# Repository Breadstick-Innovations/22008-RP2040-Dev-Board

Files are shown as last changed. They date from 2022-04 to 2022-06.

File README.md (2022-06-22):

# RP2040 Dev Board
I wanted to get myself more aquainted with JLCPCB's SMT assembly service, so I designed a board to their specs and tried to use their basic parts wherever possible, to minimize $3 loading fees for extended parts. My hope is to save time for others who are also interested in the RP2040 and JLCPCB's assembly service. If you put this design in your KiCad templates folder, it'll be quick and easy to iterate from.

 [Here's a link to the dev thread on Twitter.](https://twitter.com/RangenMichael/status/1531419000948723712?s=20&t=70S1JhFAgyq_hug58spnyA)
 
## Where To Buy
* [Tindie](https://www.tindie.com/products/breadstick/rp2040-dev-board/)
* [Breadstick.ca](https://shop.breadstick.ca/products/rp2040-dev-board)

## CircuitPython (Adafruit)
* [Firmware (.uf2)](https://circuitpython.org/board/raspberry_pi_pico/)
* [Tutorial](https://learn.adafruit.com/getting-started-with-raspberry-pi-pico-circuitpython/overview)
* [Essentials](https://learn.adafruit.com/circuitpython-essentials)
* [Docs](https://docs.circuitpython.org/en/latest/docs/index.html)
* [Mu (CircuitPython Code Editor)](https://codewith.mu/)
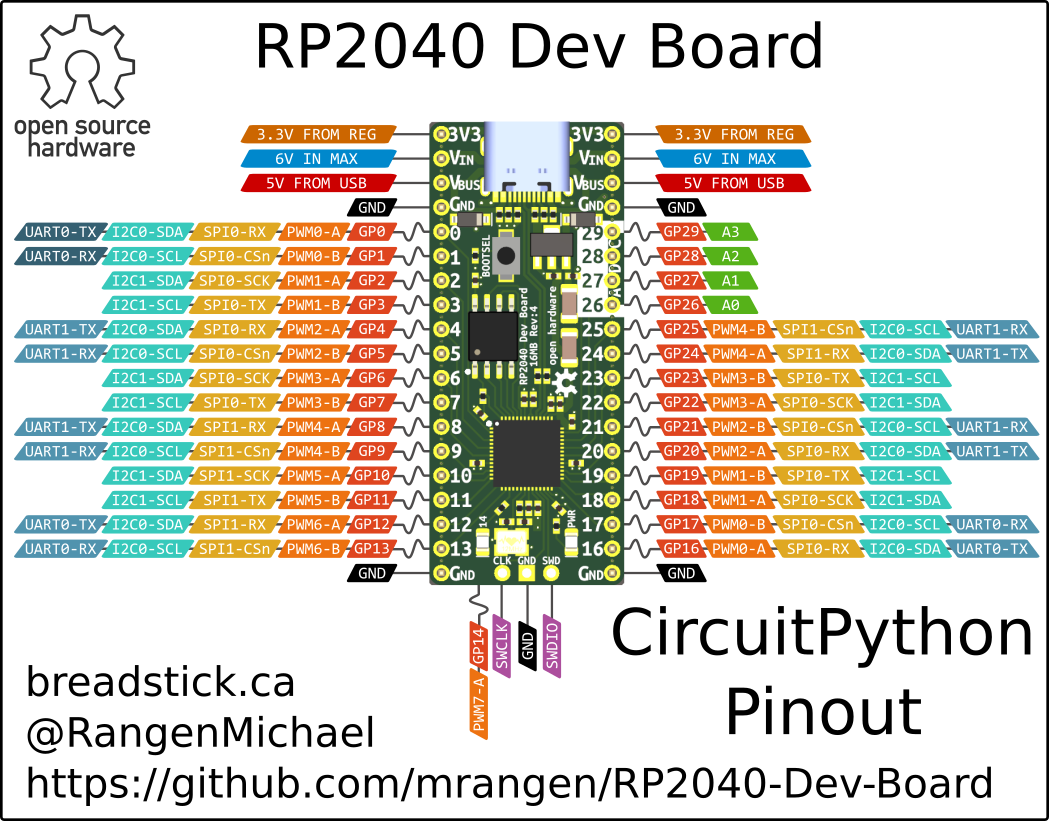
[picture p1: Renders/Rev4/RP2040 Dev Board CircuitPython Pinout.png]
CircuitPython Pinout Diagram
* 

## MicroPython
* [Firmware (.uf2)](https://micropython.org/download/rp2-pico/)
* [Tutorial](https://www.youtube.com/watch?v=JCk9QaCH5QU&list=PLEBQazB0HUyQO6rJxKr2umPCgmfAU-cqR&index=6)
* [QuickRef](https://docs.micropython.org/en/latest/rp2/quickref.html)
* [Docs](https://docs.micropython.org/en/latest/index.html)
* [Thonny (Python IDE)](https://thonny.org/)
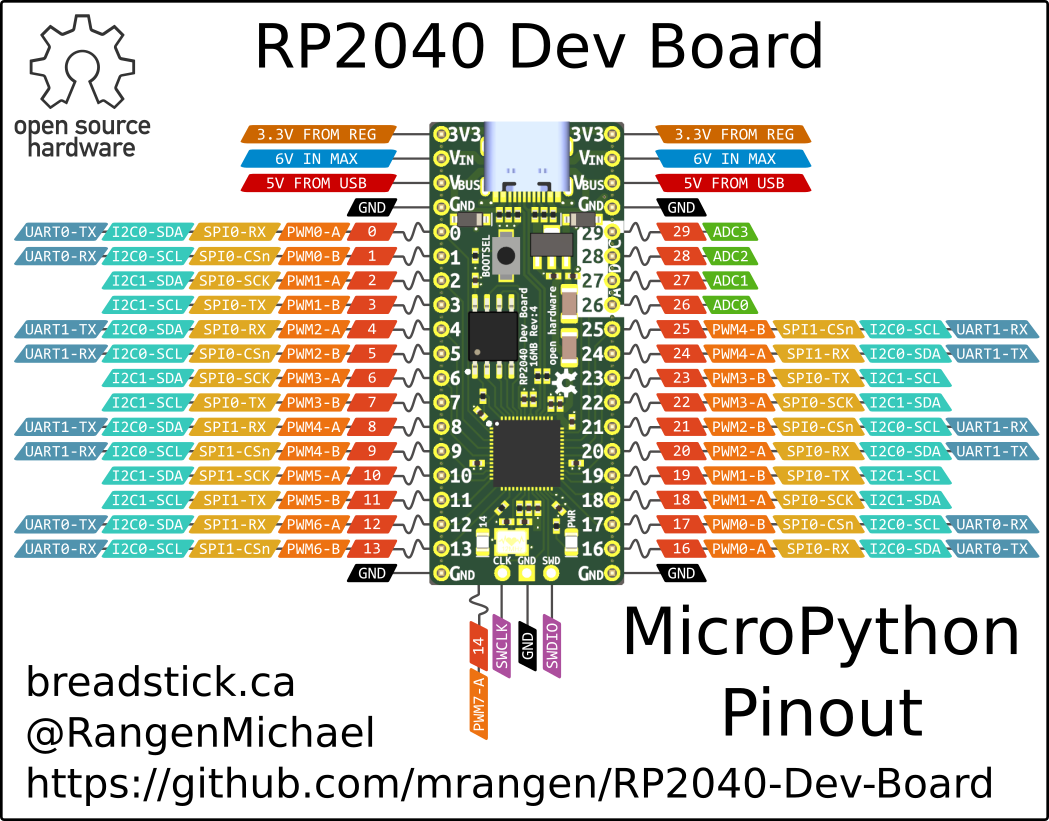
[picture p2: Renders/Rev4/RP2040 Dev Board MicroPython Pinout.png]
MicroPython Pinout Diagram


## Mechanical Drawing
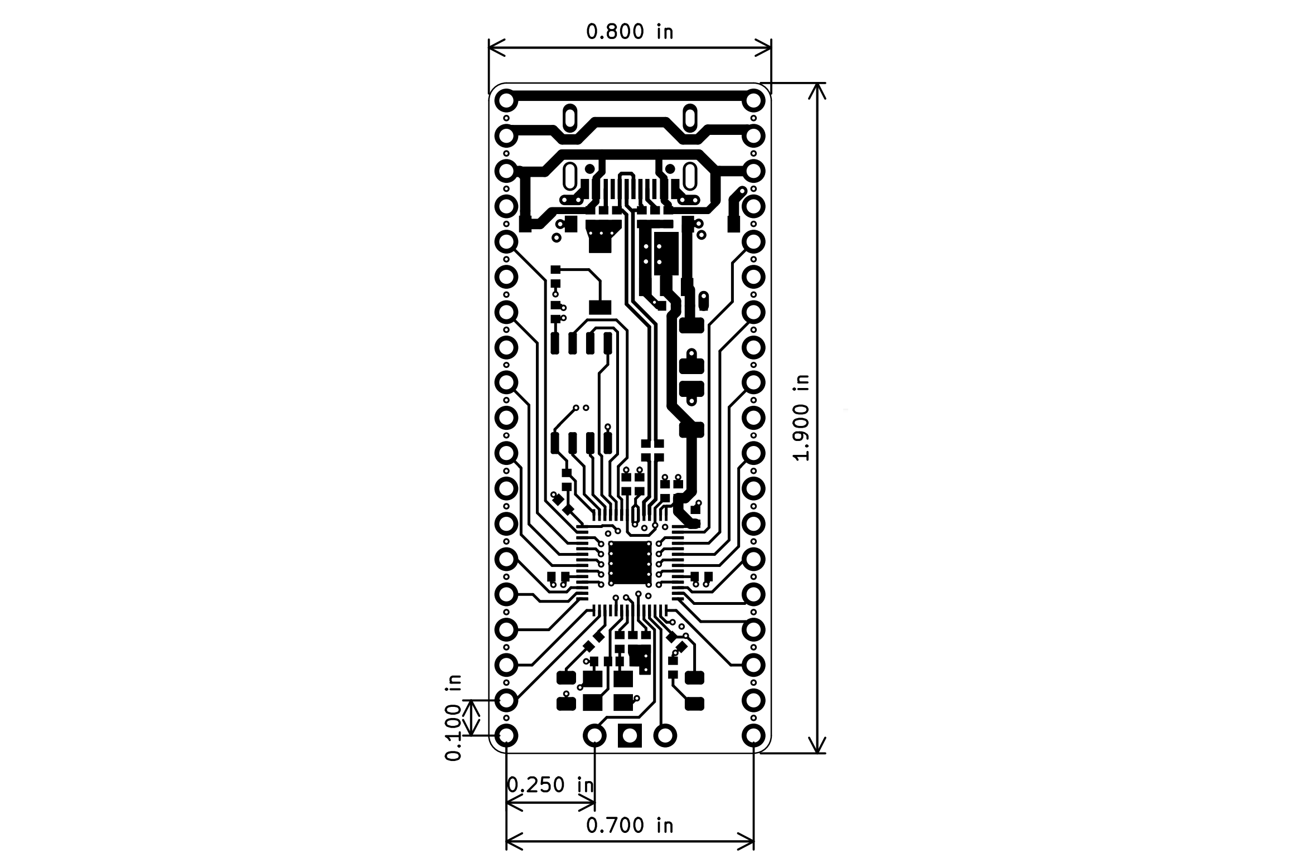
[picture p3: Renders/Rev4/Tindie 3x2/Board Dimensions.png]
Board Diagram


## Fritzing Model (Work In Progress)
Fritzing Model

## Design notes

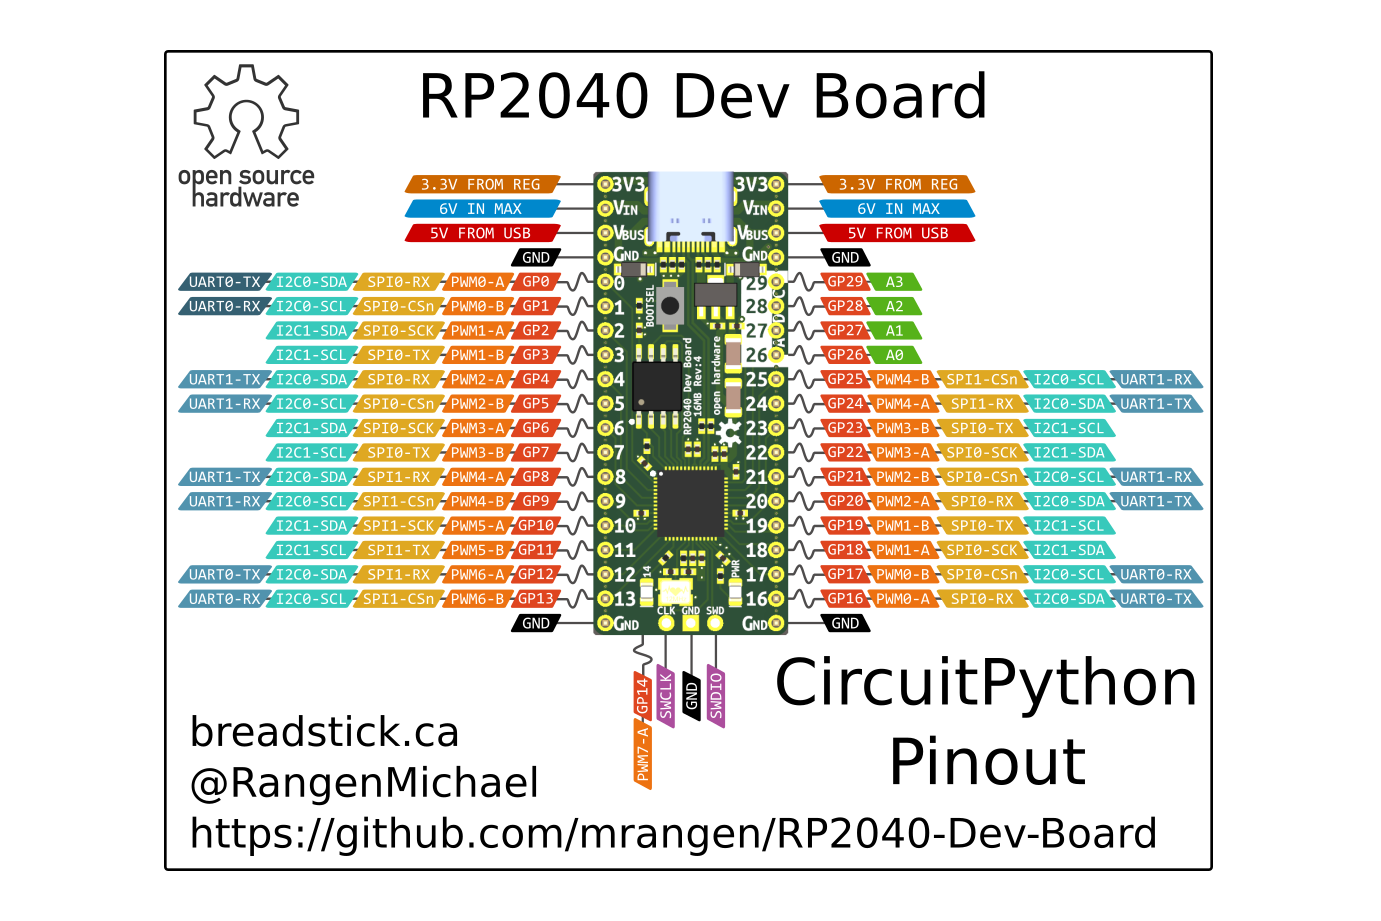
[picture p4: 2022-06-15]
Renders/Rev4/Tindie 3x2/RP2040 Dev Board CircuitPython Pinout.png

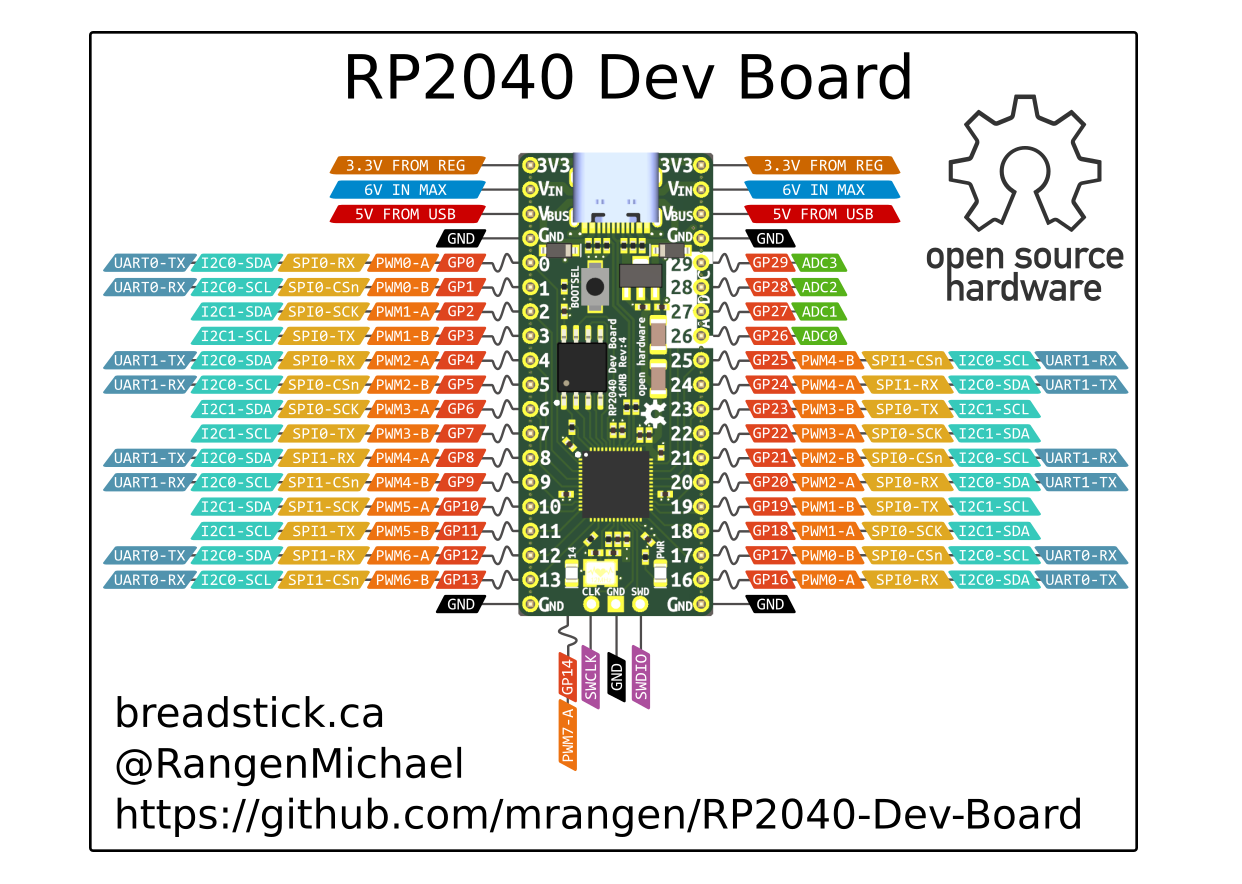
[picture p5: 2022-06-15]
Renders/Rev4/Tindie 3x2/RP2040 Dev Board Pinout.png

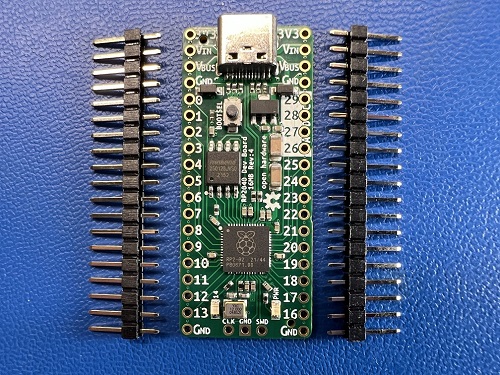
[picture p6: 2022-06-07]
Photos/Rev 4/RP2040 Dev Board with Header Pins Blue Background Front - Thumb.JPG

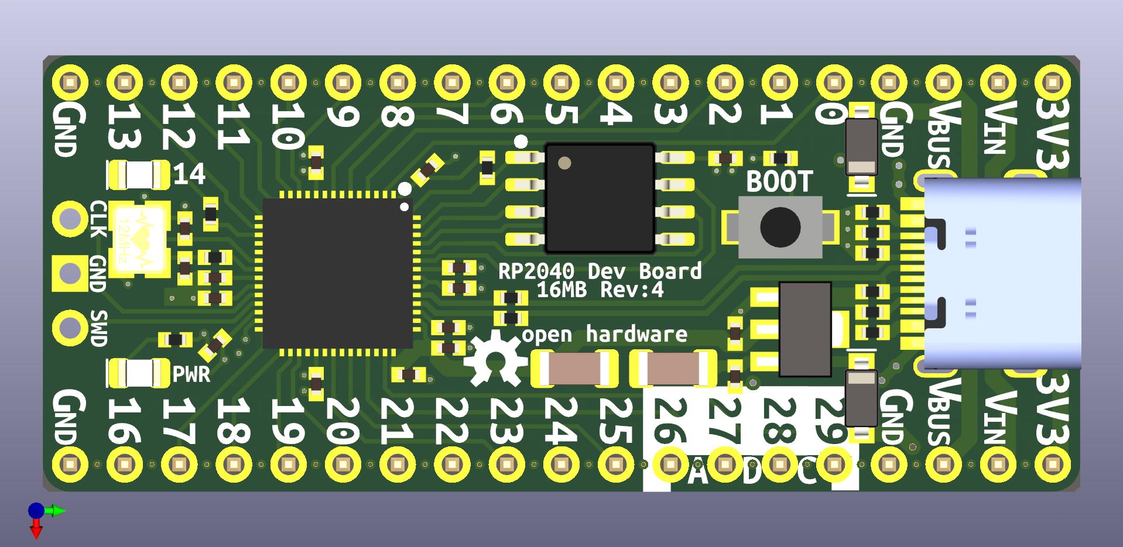
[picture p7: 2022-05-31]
Renders/Rev4/RP2040 Dev Board Front.jpg

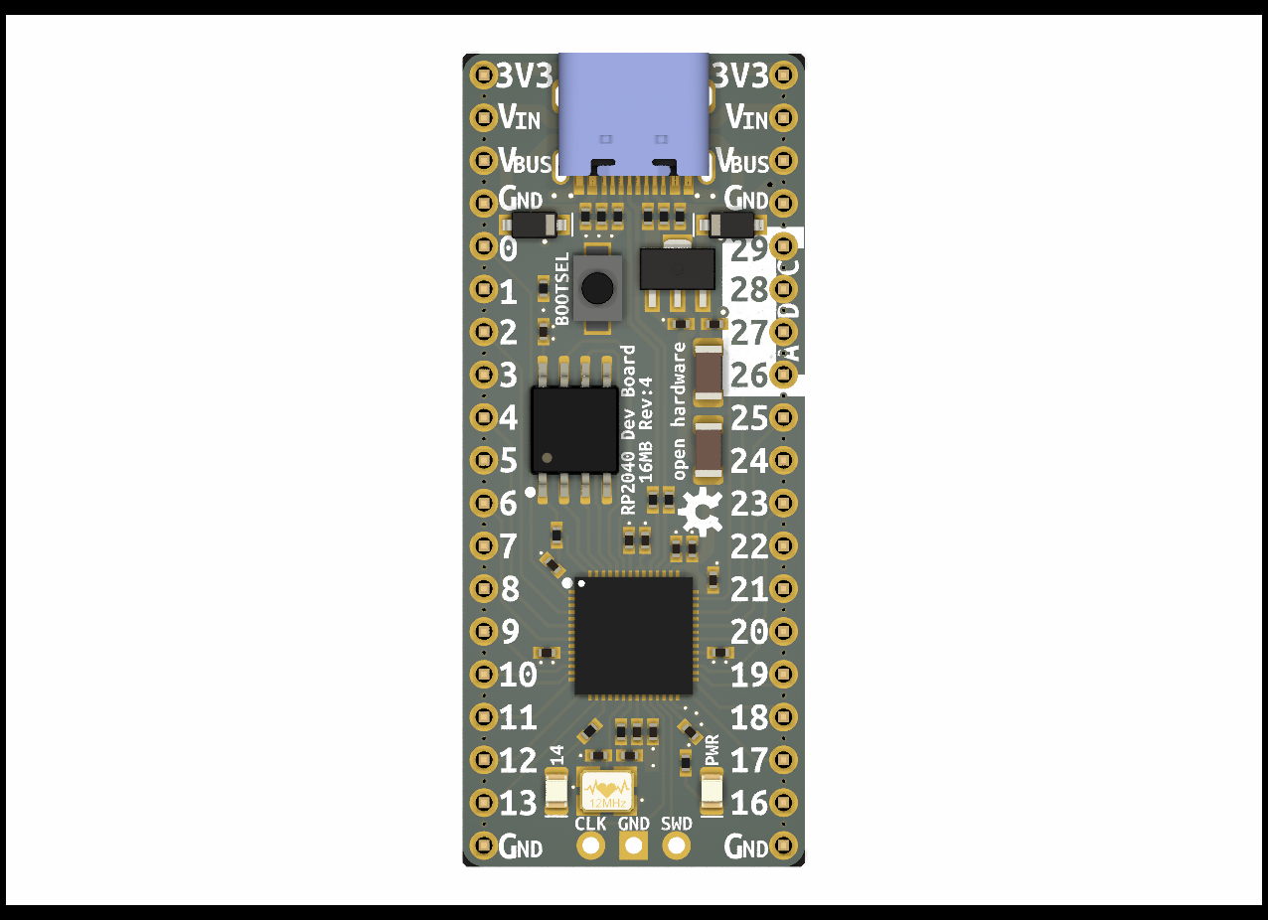
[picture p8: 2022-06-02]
Renders/Rev4/RP2040 Dev Board Front Isometric White Background Raytraced.png

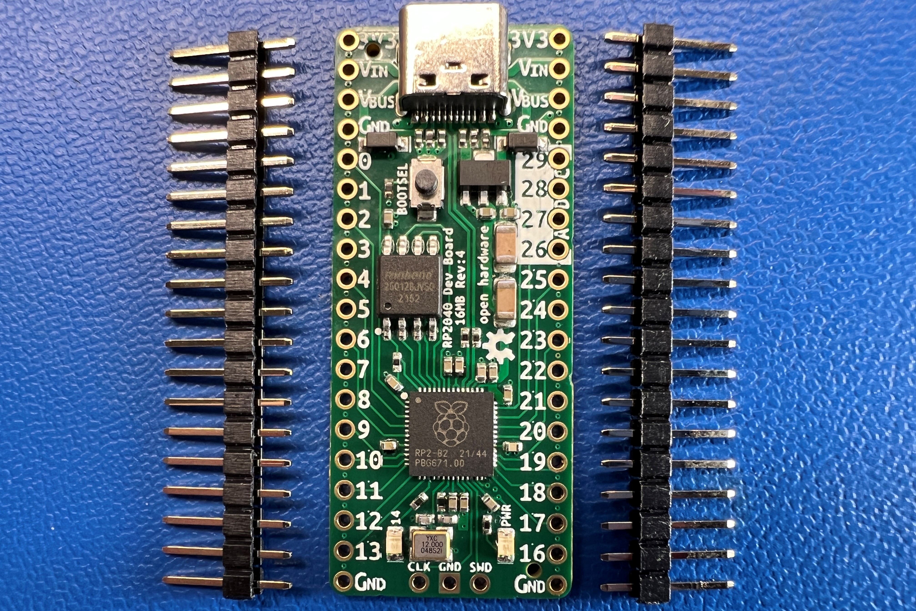
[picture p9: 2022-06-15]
Photos/Rev 4/Tindie 3x2/RP2040 Dev Board with Header Pins Blue Background Front.JPG

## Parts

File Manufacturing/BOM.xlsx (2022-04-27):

Comment | Designator | Footprint | LCSC Part Number
10uF | C201, C202, C204, C205, C207, C208, C212, C213, C215, C216, C218, C219, C221, C222 | 0402 | C15525
30pF | C203, C206 | 0402 | C1570
100uF | C209, C210 | 1206 | C15008
LED_Filled | D101, D102 | 0805 | C2297
SHOTTKY | D103, D104 | SOD-123 | C8598
ESD_TVS | D201, D202, D203, D205 | 0402 | C316049
Conn_01x19 | J101, J102 | Connector_PinHeader_2.54mm:PinHeader_1x19_P2.54mm_Vertical | DNP
Conn_01x03 | J103 | Connector_PinHeader_2.54mm:PinHeader_1x03_P2.54mm_Horizontal | DNP
TYPE-C-31-M-12 | J201 | TYPE-C-31-M-12:HRO_TYPE-C-31-M-12 | C165948
10k | R101, R102, R213 | 0402 | C25744
1k | R201, R211 | 0402 | C11702
27 | R203, R204 | 0402 | C25100
5k1 | R212, R214 | 0402 | C25905
~{USB_BOOT} | SW202 | SW-SMD-2_2.9x3.9x1.7 | C843669
AZ1117R-3.3TRE1 | U201 | SOT-89-3 | C108493
RP2040 | U202 | QFN40P700X700X90-57N | C2040
W25Q128JVS | U205 | SOIC-8_5.23x5.23mm_P1.27mm | C97521
12MHz ±30ppm 20pF 80Ω | Y201 | SMD-3225_4P | C9002

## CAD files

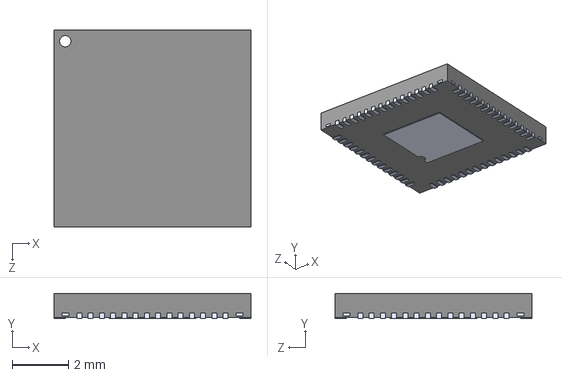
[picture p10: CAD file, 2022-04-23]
Snap EDA/RP2040/RP2040.step
7.00 x 0.9 x 7.00 mm

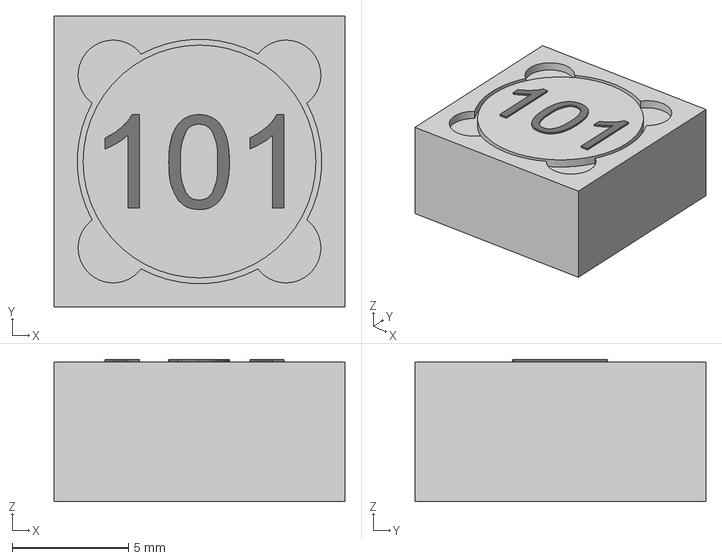
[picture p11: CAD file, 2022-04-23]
Snap EDA/SWRB1205S-101MT v2.step
12.5 x 12.5 x 6.10 mm

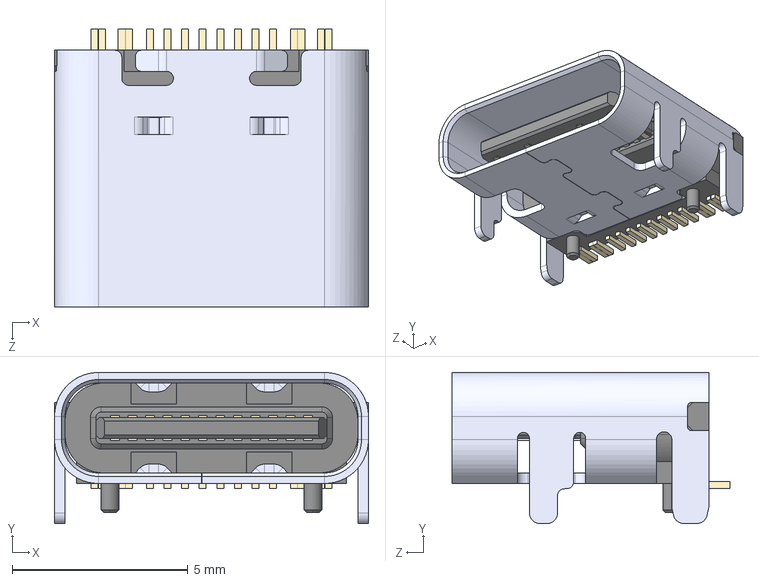
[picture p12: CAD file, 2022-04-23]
Snap EDA/TYPE-C-31-M-12/TYPE-C-31-M-12.step
8.94 x 4.30 x 7.90 mm

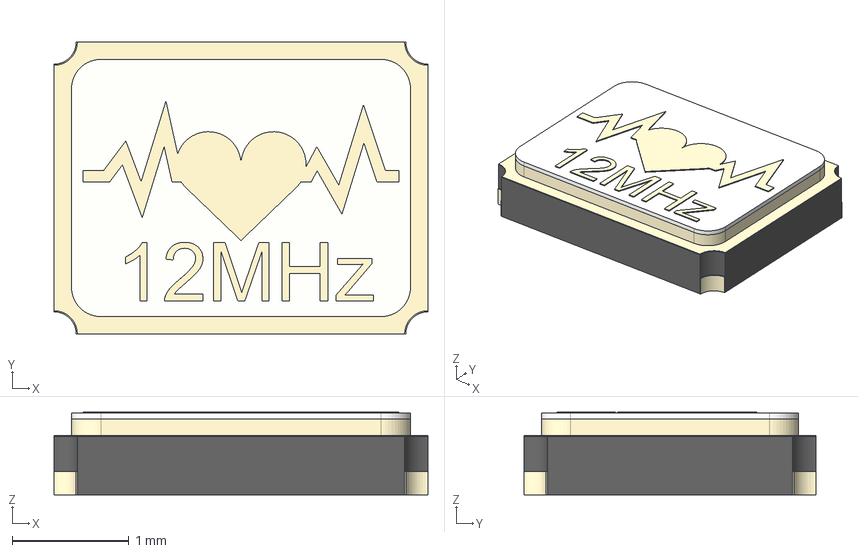
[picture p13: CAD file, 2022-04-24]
Snap EDA/X322516MLB4SI/Crystal3225_24GND.step
3.20 x 2.50 x 0.71 mm

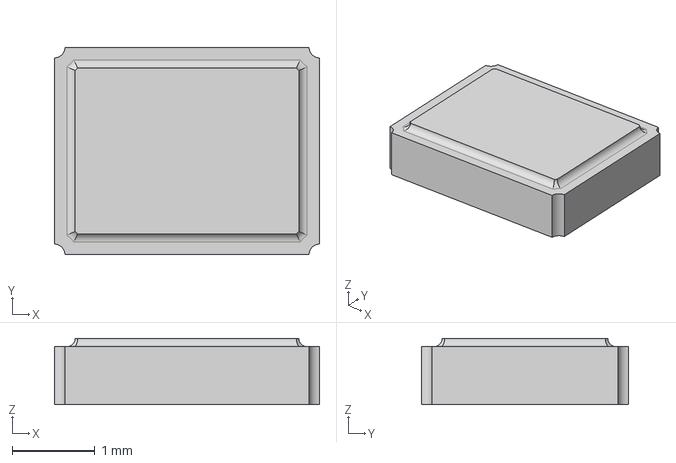
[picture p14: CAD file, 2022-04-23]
Snap EDA/7V12000018 v4.step
3.20 x 2.50 x 0.8 mm

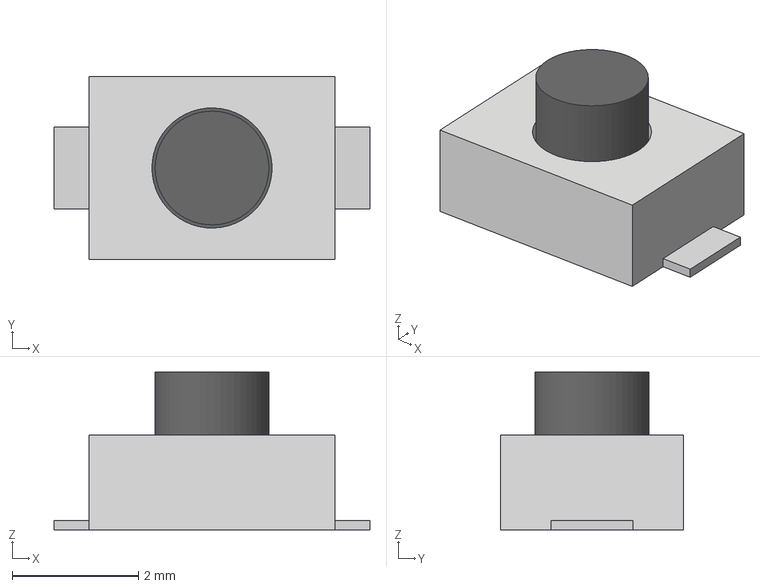
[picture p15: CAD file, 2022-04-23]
Snap EDA/GT-TC029B-H025-L1N v1.step
5.00 x 2.90 x 2.50 mm

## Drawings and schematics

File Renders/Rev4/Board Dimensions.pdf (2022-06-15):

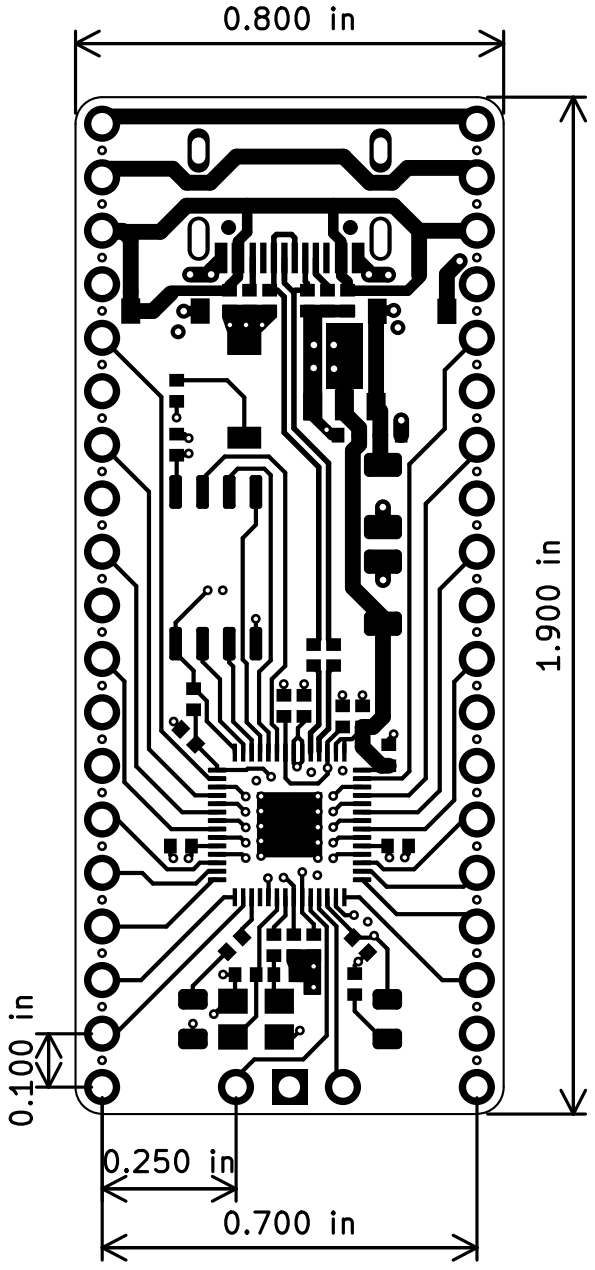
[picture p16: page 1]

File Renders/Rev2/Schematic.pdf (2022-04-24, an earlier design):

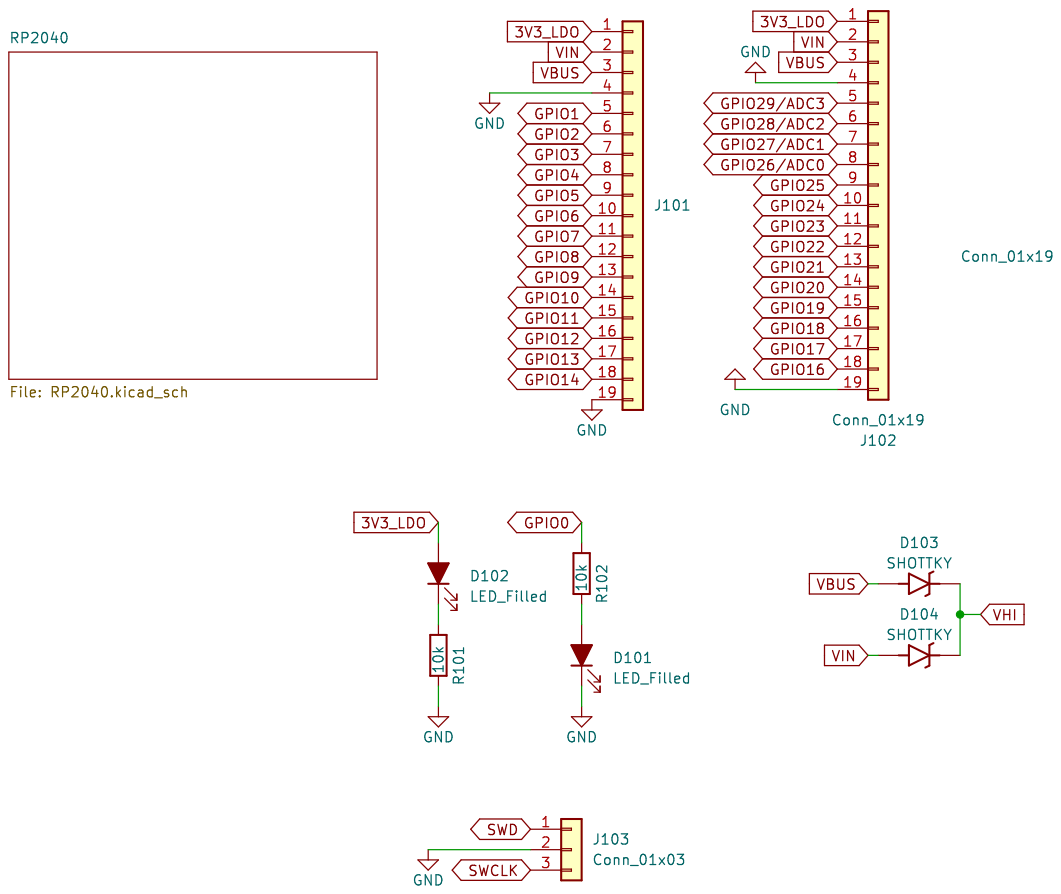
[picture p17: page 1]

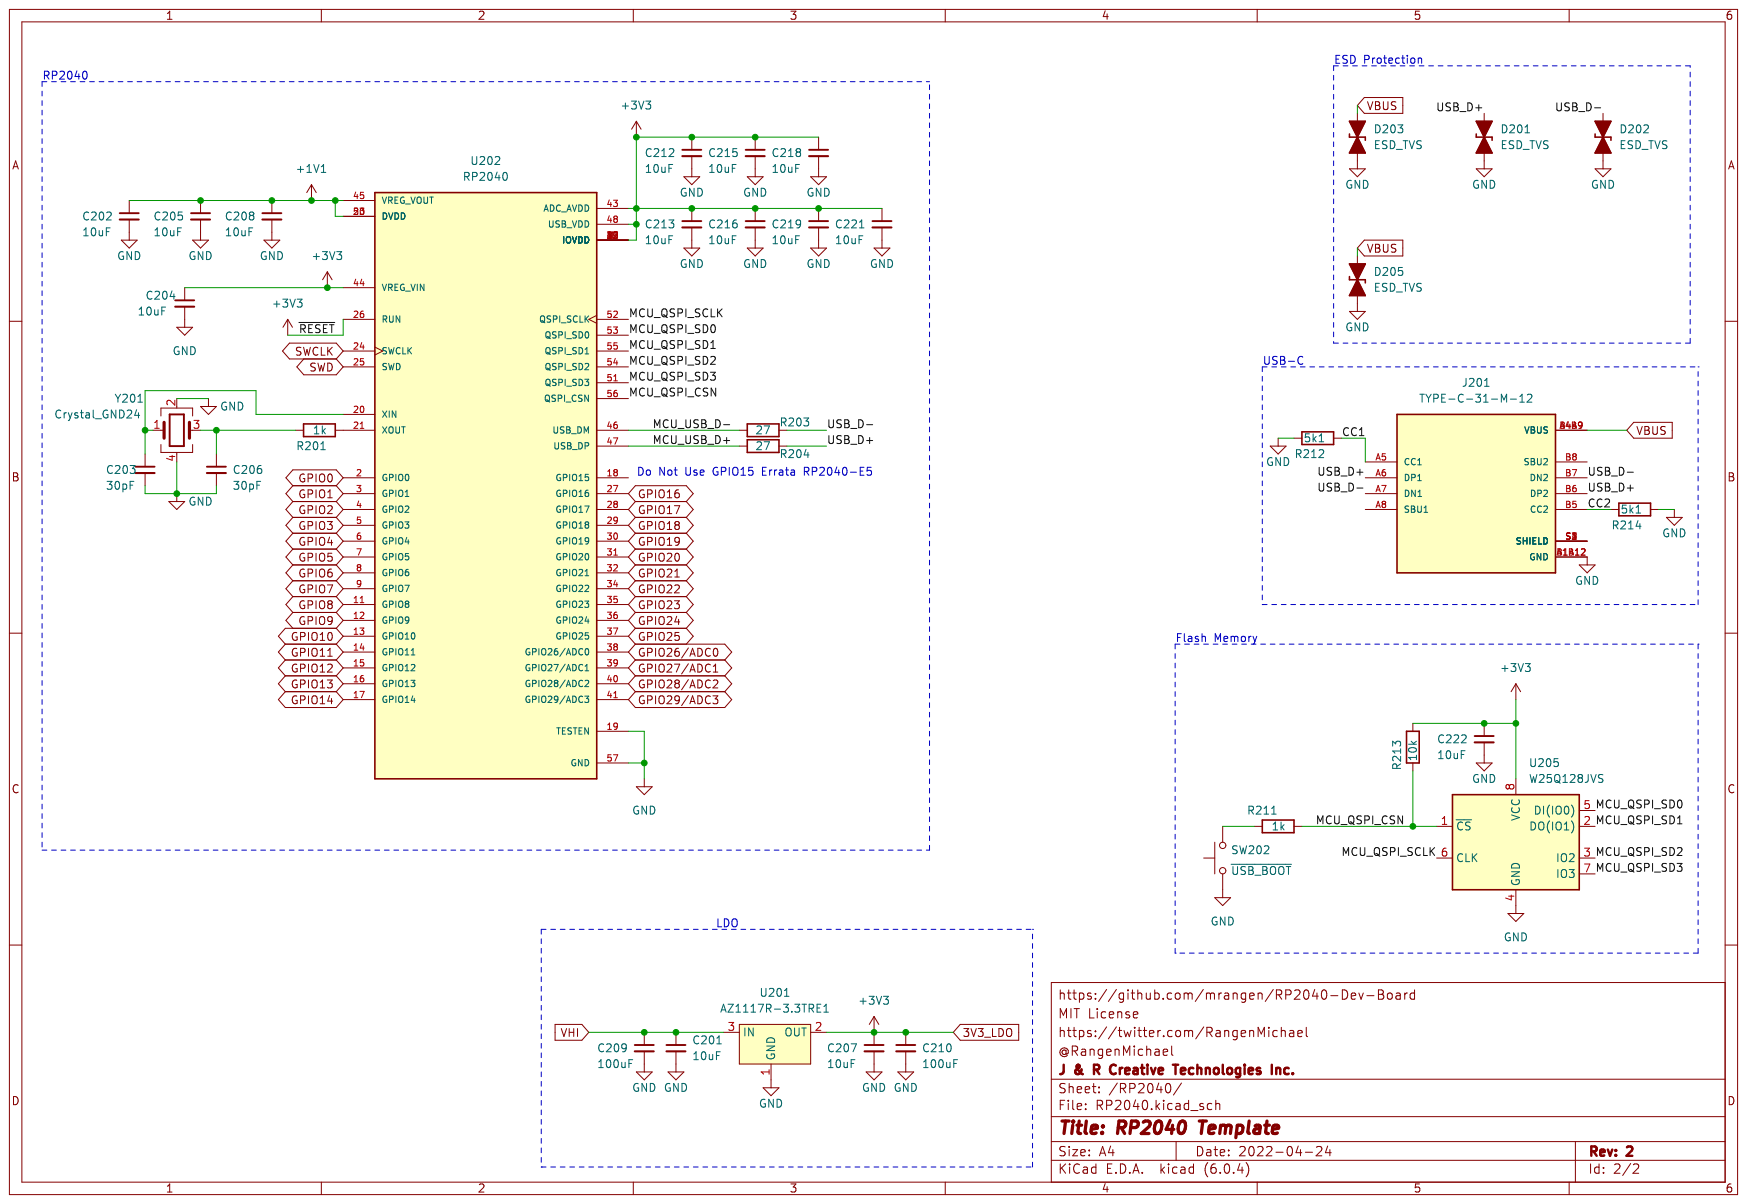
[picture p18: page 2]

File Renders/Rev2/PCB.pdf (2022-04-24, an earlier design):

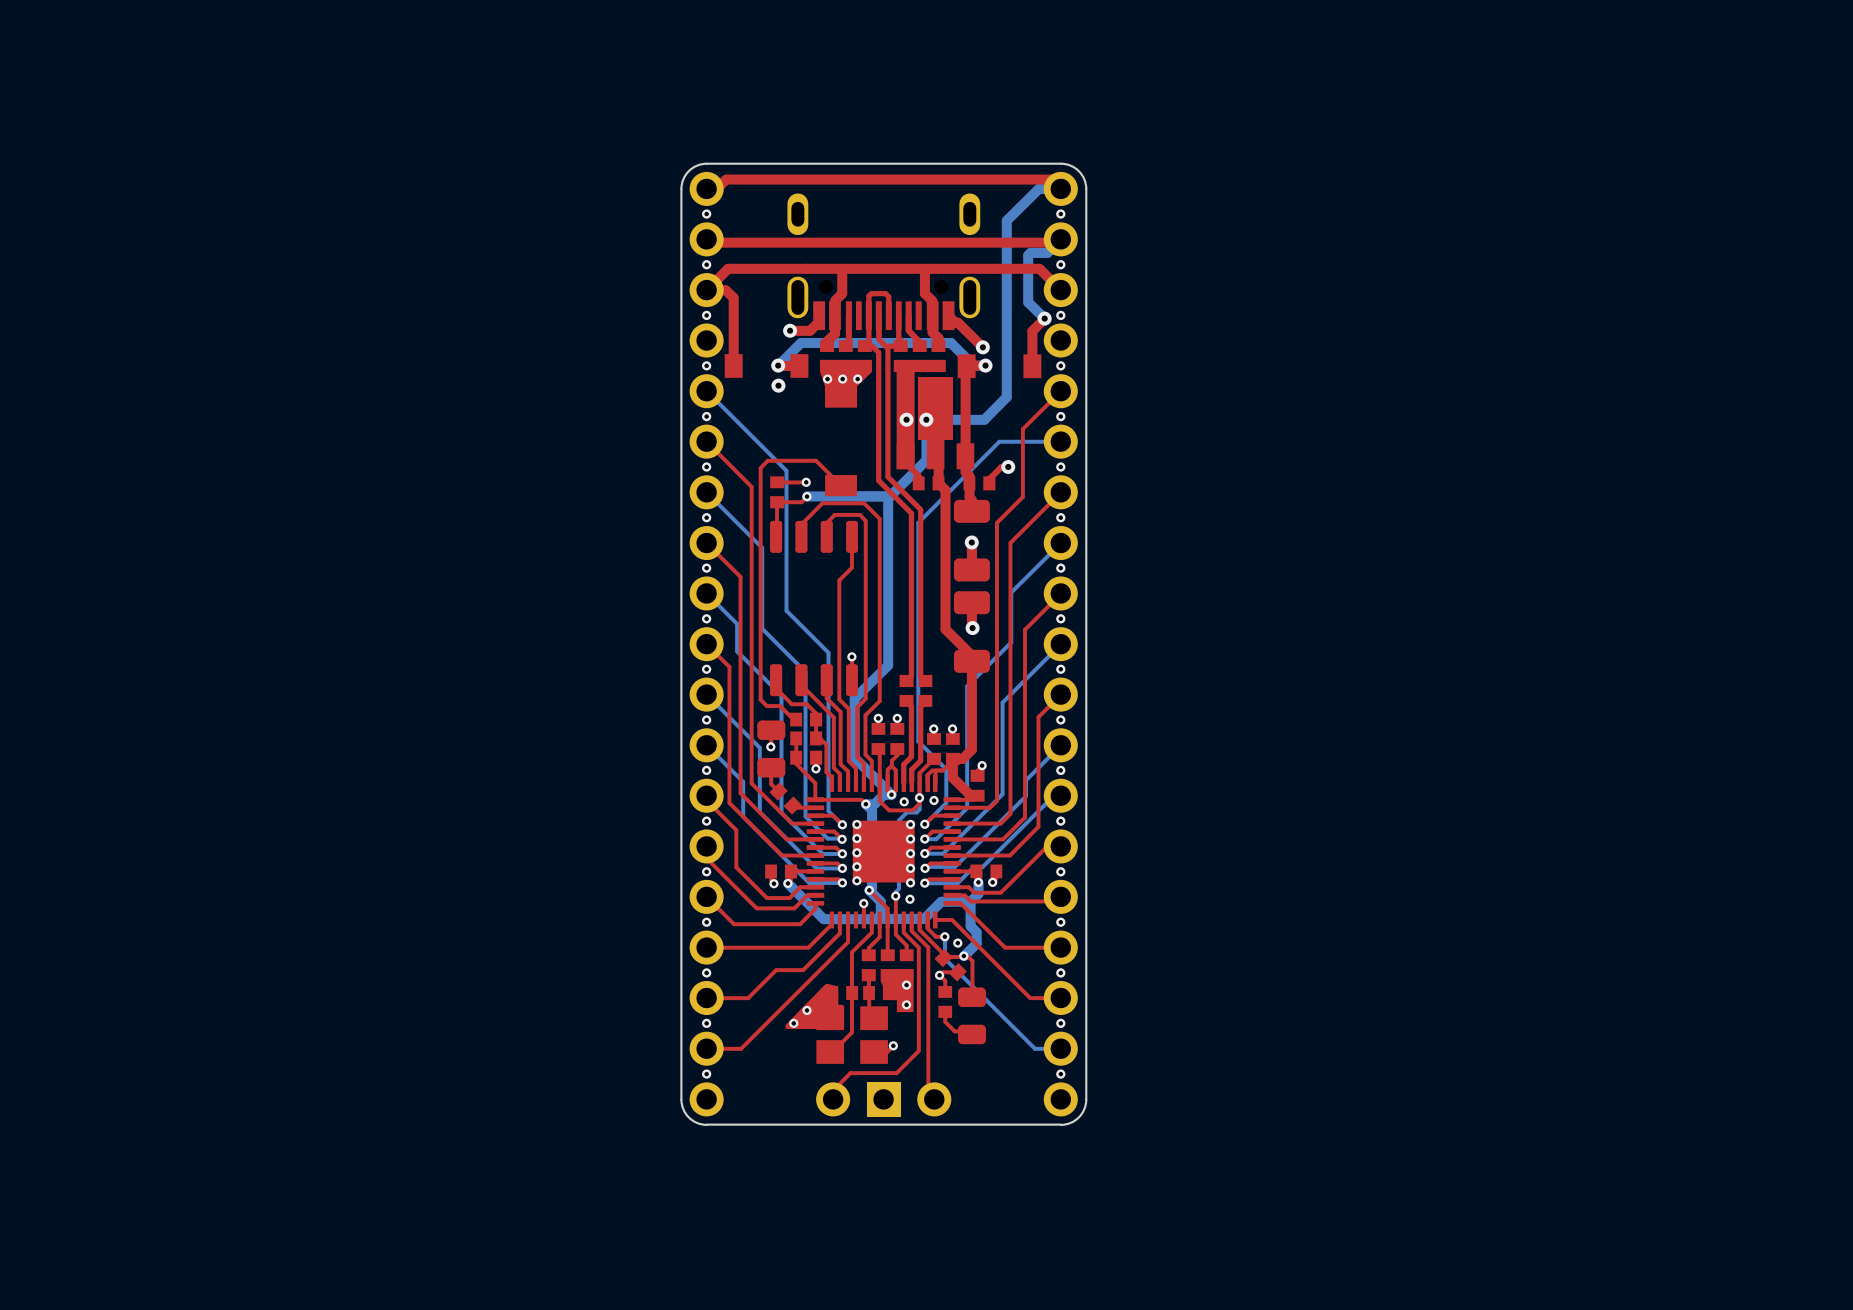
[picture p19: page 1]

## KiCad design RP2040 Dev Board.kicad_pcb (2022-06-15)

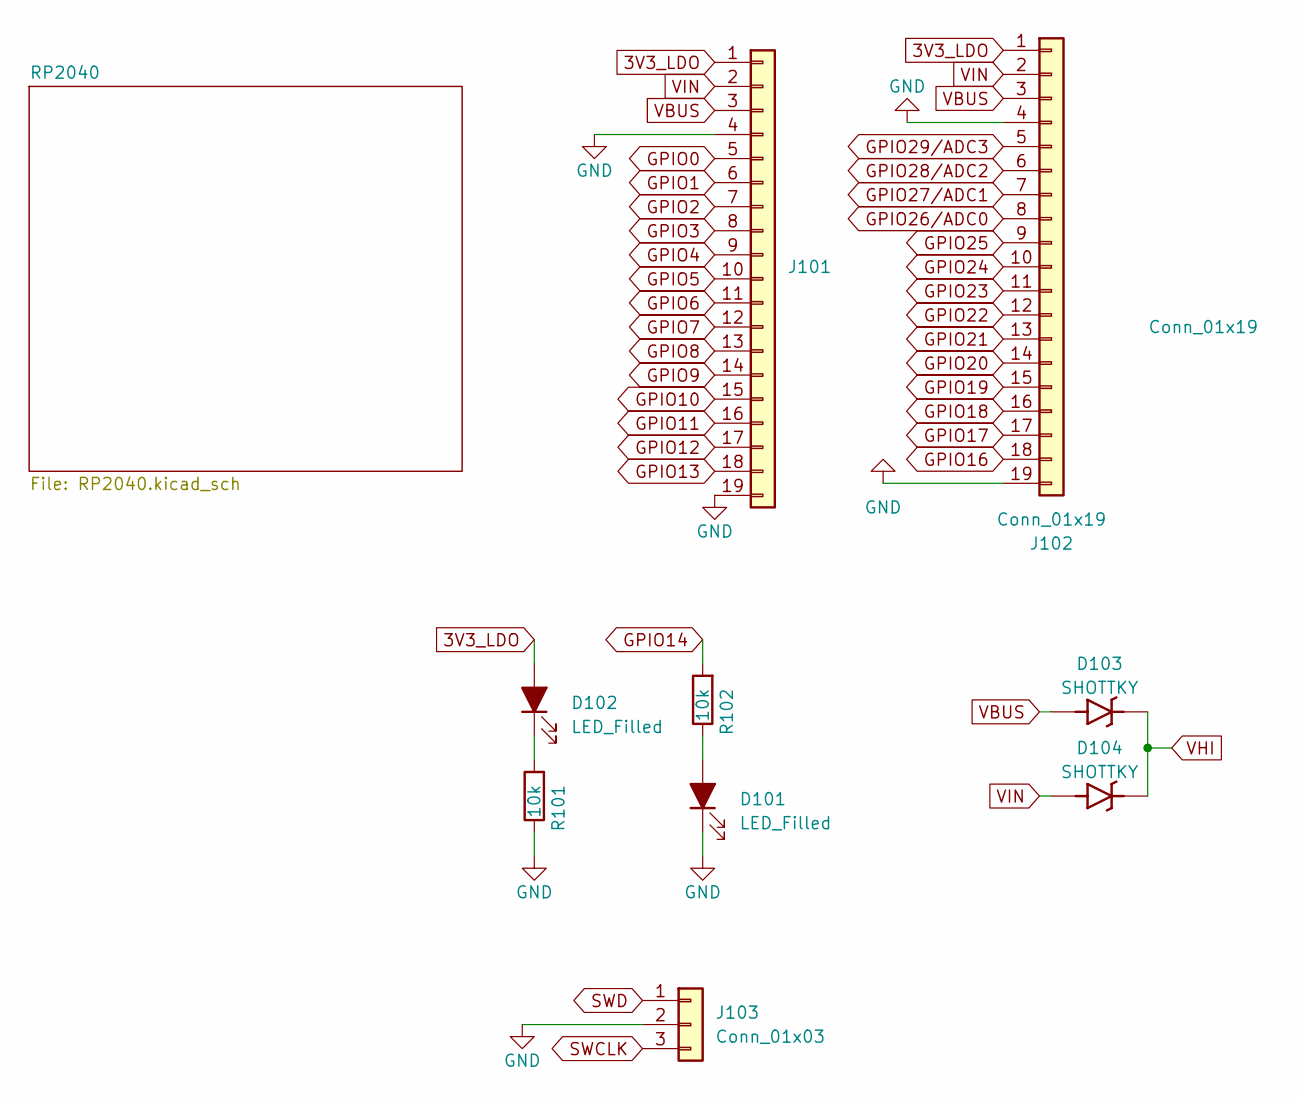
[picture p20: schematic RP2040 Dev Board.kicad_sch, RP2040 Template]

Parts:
D101, D102: LED_Filled; LED_0805_2012Metric; JLCPCB P/N C2297
D103, D104: SHOTTKY; D_SOD-123; JLCPCB P/N C8598
J101, J102: Conn_01x19; PinHeader_1x19_P2.54mm_Vertical
J103: Conn_01x03; PinHeader_1x03_P2.54mm_Horizontal
R101, R102: 10k; Perfect_0402_Resistor; JLCPCB P/N C25744

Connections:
3V3_LDO: D102.2 (A), J101.1, J102.1; also elsewhere on the board
GND: D101.1 (K), J101.4, J101.19, J102.4, J102.19, J103.2, R101.1; also elsewhere on the board
GPIO0: J101.5; also elsewhere on the board
GPIO1: J101.6; also elsewhere on the board
GPIO2: J101.7; also elsewhere on the board
GPIO3: J101.8; also elsewhere on the board
GPIO4: J101.9; also elsewhere on the board
GPIO5: J101.10; also elsewhere on the board
GPIO6: J101.11; also elsewhere on the board
GPIO7: J101.12; also elsewhere on the board
GPIO8: J101.13; also elsewhere on the board
GPIO9: J101.14; also elsewhere on the board
GPIO10: J101.15; also elsewhere on the board
GPIO11: J101.16; also elsewhere on the board
GPIO12: J101.17; also elsewhere on the board
GPIO13: J101.18; also elsewhere on the board
GPIO14: R102.2; also elsewhere on the board
GPIO16: J102.18; also elsewhere on the board
GPIO17: J102.17; also elsewhere on the board
GPIO18: J102.16; also elsewhere on the board
GPIO19: J102.15; also elsewhere on the board
GPIO20: J102.14; also elsewhere on the board
GPIO21: J102.13; also elsewhere on the board
GPIO22: J102.12; also elsewhere on the board
GPIO23: J102.11; also elsewhere on the board
GPIO24: J102.10; also elsewhere on the board
GPIO25: J102.9; also elsewhere on the board
GPIO26/ADC0: J102.8; also elsewhere on the board
GPIO27/ADC1: J102.7; also elsewhere on the board
GPIO28/ADC2: J102.6; also elsewhere on the board
GPIO29/ADC3: J102.5; also elsewhere on the board
unnamed: D101.2 (A), R102.1
unnamed: D102.1 (K), R101.2
SWCLK: J103.3; also elsewhere on the board
SWD: J103.1; also elsewhere on the board
VBUS: D103.2 (A), J101.3, J102.3; also elsewhere on the board
VHI: D103.1 (C), D104.1 (C); also elsewhere on the board
VIN: D104.2 (A), J101.2, J102.2

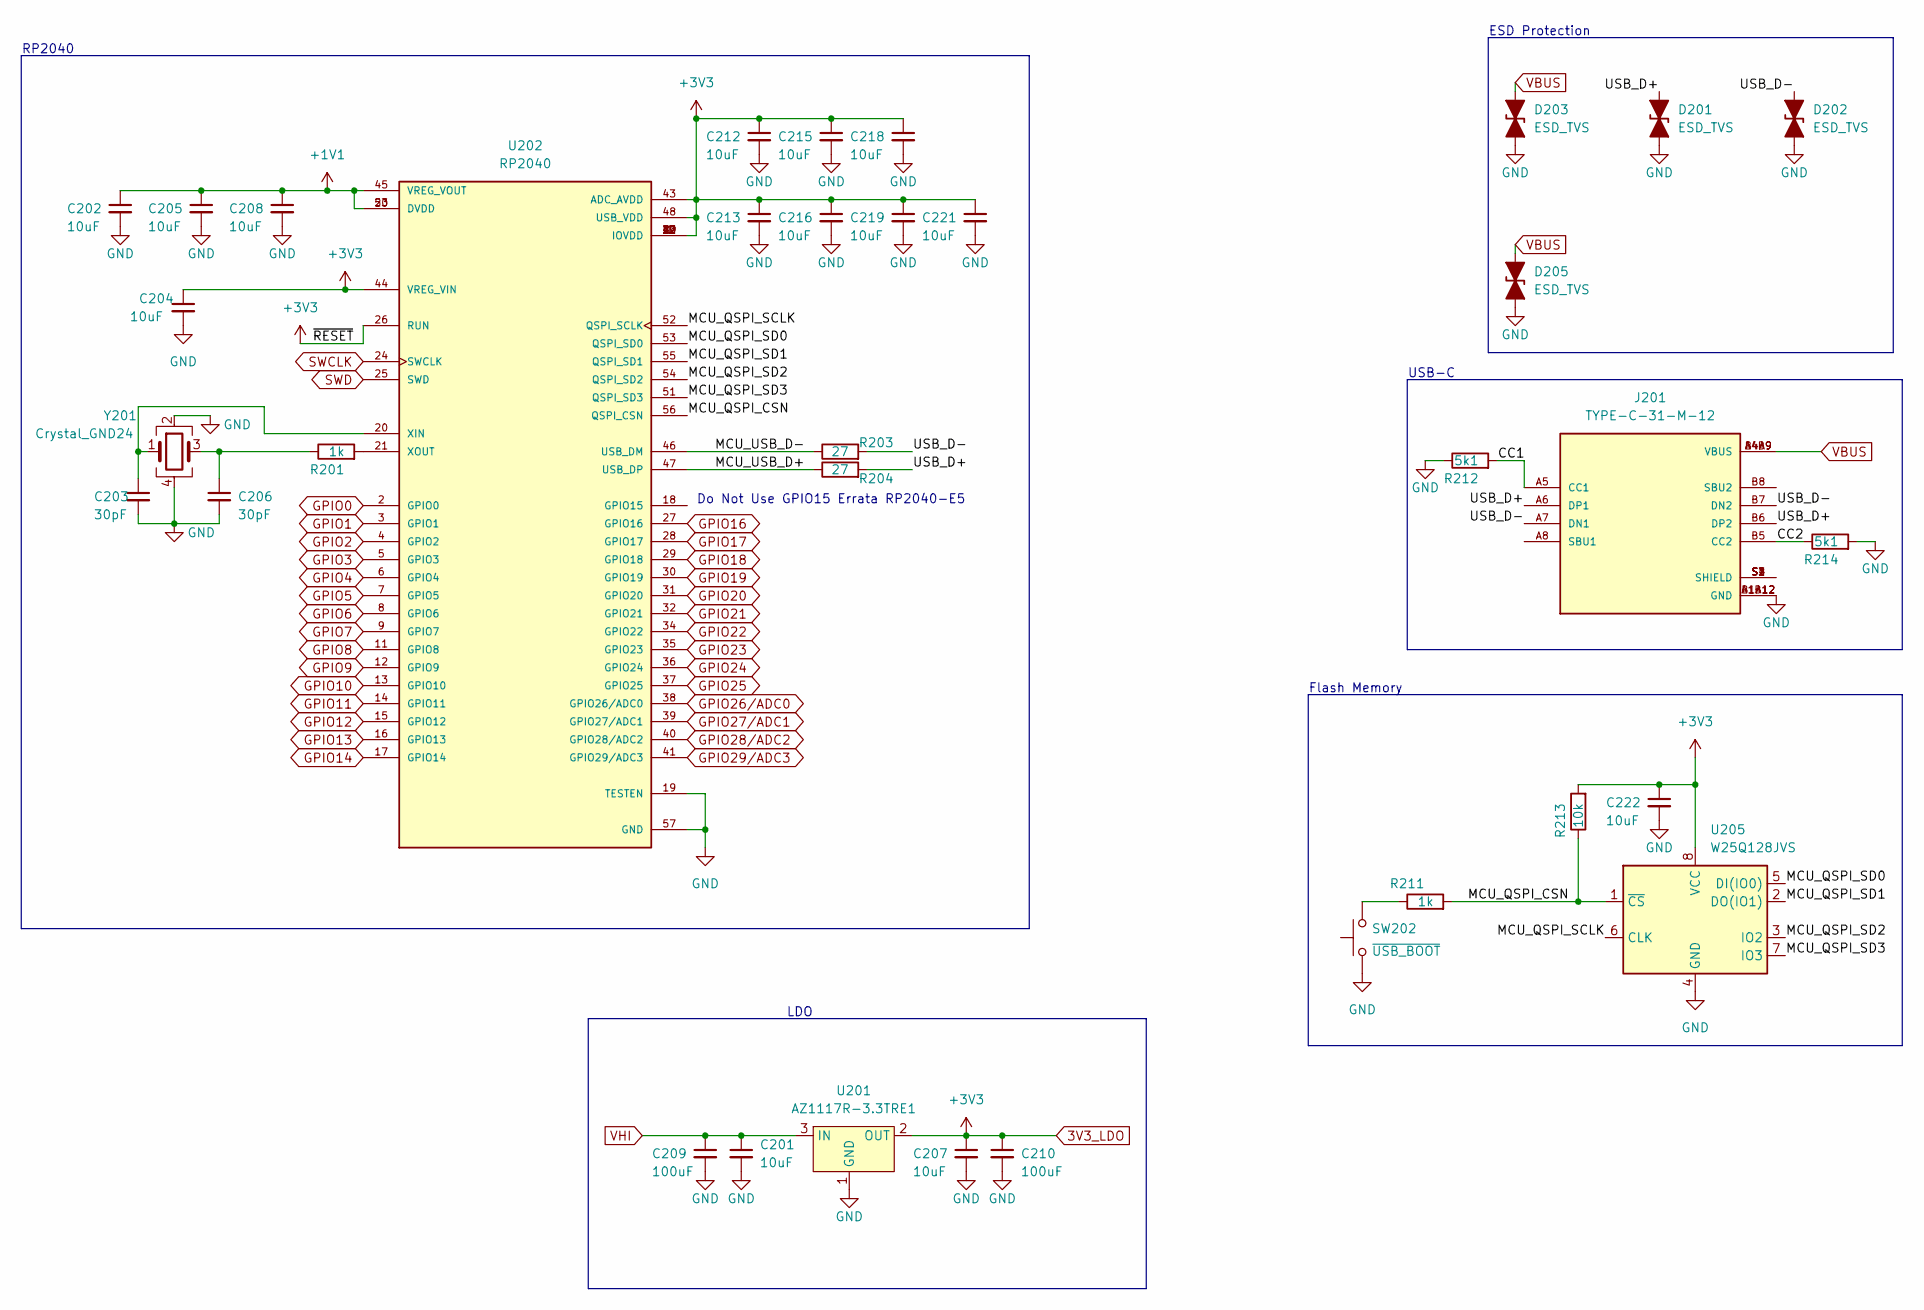
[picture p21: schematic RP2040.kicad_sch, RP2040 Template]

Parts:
C201, C202, C204, C205, C207, C208, C212, C213, C215, C216, C218, C219, C221, C222: 10uF; Perfect_0402_Cap; JLCPCB P/N C15525
C203, C206: 30pF; Perfect_0402_Cap; JLCPCB P/N C1570
C209, C210: 100uF; C_1206_3216Metric; JLCPCB P/N C15008
D201, D202, D203, D205: ESD_TVS; Perfect_0402_Resistor; JLCPCB P/N C316049
J201: TYPE-C-31-M-12; HRO_TYPE-C-31-M-12; PARTREV A; JLCPCB P/N C165948
R201, R211: 1k; Perfect_0402_Resistor; JLCPCB P/N C11702
R203, R204: 27; Perfect_0402_Resistor; JLCPCB P/N C25100
R212, R214: 5k1; Perfect_0402_Resistor; JLCPCB P/N C25905
R213: 10k; Perfect_0402_Resistor; JLCPCB P/N C25744
SW202: ~{USB_BOOT}; GT-TC029B-H025-L1N; JLCPCB P/N C843669
U201: AZ1117R-3.3TRE1; SOT-89-3; JLCPCB P/N C108493
U202: RP2040; QFN40P700X700X90-57N; PARTREV 1.6.1; JLCPCB P/N C2040
U205: W25Q128JVS; SOIC-8_5.23x5.23mm_P1.27mm; JLCPCB P/N C97521
Y201: Crystal_GND24; OSC_X322516MLB4SI; JLCPCB P/N C9002

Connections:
3V3_LDO: C204.1, C207.1, C210.1, C212.1, C213.1, C215.1, C216.1, C218.1, C219.1, C221.1, C222.1, R213.2, U201.2 (OUT), U202.1 (IOVDD), U202.10 (IOVDD), U202.22 (IOVDD), U202.26 (RUN), U202.33 (IOVDD), U202.42 (IOVDD), U202.43 (ADC_AVDD), U202.44 (VREG_VIN), U202.48 (USB_VDD), U202.49 (IOVDD), U205.8 (VCC); also elsewhere on the board
+1V1: C202.1, C205.1, C208.1, U202.23 (DVDD), U202.45 (VREG_VOUT), U202.50 (DVDD)
/RP2040/CC1: J201.A5 (CC1), R212.2
/RP2040/CC2: J201.B5 (CC2), R214.1
/RP2040/MCU_QSPI_CSN: R211.2, R213.1, U202.56 (QSPI_CSN), U205.1 (~CS)
/RP2040/MCU_QSPI_SCLK: U202.52 (QSPI_SCLK), U205.6 (CLK)
/RP2040/MCU_QSPI_SD0: U202.53 (QSPI_SD0), U205.5 (DI(IO0))
/RP2040/MCU_QSPI_SD1: U202.55 (QSPI_SD1), U205.2 (DO(IO1))
/RP2040/MCU_QSPI_SD2: U202.54 (QSPI_SD2), U205.3 (IO2)
/RP2040/MCU_QSPI_SD3: U202.51 (QSPI_SD3), U205.7 (IO3)
/RP2040/MCU_USB_D+: R204.1, U202.47 (USB_DP)
/RP2040/MCU_USB_D-: R203.1, U202.46 (USB_DM)
/RP2040/USB_D+: D201.2 (A2), J201.A6 (DP1), J201.B6 (DP2), R204.2
/RP2040/USB_D-: D202.2 (A2), J201.A7 (DN1), J201.B7 (DN2), R203.2
GND: C201.2, C202.2, C203.2, C204.2, C205.2, C206.2, C207.2, C208.2, C209.2, C210.2, C212.2, C213.2, C215.2, C216.2, C218.2, C219.2, C221.2, C222.2, D201.1 (A1), D202.1 (A1), D203.1 (A1), D205.1 (A1), J201.A1B12 (GND), J201.B1A12 (GND), R212.1, R214.2, SW202.1, U201.1 (GND), U202.19 (TESTEN), U202.57 (GND), U205.4 (GND), Y201.2, Y201.4; also elsewhere on the board
GPIO0: U202.2 (GPIO0); also elsewhere on the board
GPIO1: U202.3 (GPIO1); also elsewhere on the board
GPIO2: U202.4 (GPIO2); also elsewhere on the board
GPIO3: U202.5 (GPIO3); also elsewhere on the board
GPIO4: U202.6 (GPIO4); also elsewhere on the board
GPIO5: U202.7 (GPIO5); also elsewhere on the board
GPIO6: U202.8 (GPIO6); also elsewhere on the board
GPIO7: U202.9 (GPIO7); also elsewhere on the board
GPIO8: U202.11 (GPIO8); also elsewhere on the board
GPIO9: U202.12 (GPIO9); also elsewhere on the board
GPIO10: U202.13 (GPIO10); also elsewhere on the board
GPIO11: U202.14 (GPIO11); also elsewhere on the board
GPIO12: U202.15 (GPIO12); also elsewhere on the board
GPIO13: U202.16 (GPIO13); also elsewhere on the board
GPIO14: U202.17 (GPIO14); also elsewhere on the board
GPIO16: U202.27 (GPIO16); also elsewhere on the board
GPIO17: U202.28 (GPIO17); also elsewhere on the board
GPIO18: U202.29 (GPIO18); also elsewhere on the board
GPIO19: U202.30 (GPIO19); also elsewhere on the board
GPIO20: U202.31 (GPIO20); also elsewhere on the board
GPIO21: U202.32 (GPIO21); also elsewhere on the board
GPIO22: U202.34 (GPIO22); also elsewhere on the board
GPIO23: U202.35 (GPIO23); also elsewhere on the board
GPIO24: U202.36 (GPIO24); also elsewhere on the board
GPIO25: U202.37 (GPIO25); also elsewhere on the board
GPIO26/ADC0: U202.38 (GPIO26/ADC0); also elsewhere on the board
GPIO27/ADC1: U202.39 (GPIO27/ADC1); also elsewhere on the board
GPIO28/ADC2: U202.40 (GPIO28/ADC2); also elsewhere on the board
GPIO29/ADC3: U202.41 (GPIO29/ADC3); also elsewhere on the board
unnamed: C203.1, U202.20 (XIN), Y201.1
unnamed: C206.1, R201.1, Y201.3
unnamed: J201.S1 (SHIELD), J201.S2 (SHIELD), J201.S3 (SHIELD), J201.S4 (SHIELD)
unnamed: R201.2, U202.21 (XOUT)
unnamed: R211.1, SW202.2
SWCLK: U202.24 (SWCLK); also elsewhere on the board
SWD: U202.25 (SWD); also elsewhere on the board
VBUS: D203.2 (A2), D205.2 (A2), J201.A4B9 (VBUS), J201.B4A9 (VBUS); also elsewhere on the board
VHI: C201.1, C209.1, U201.3 (IN); also elsewhere on the board

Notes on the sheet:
RP2040
Flash Memory
LDO
ESD Protection
USB-C
Do Not Use GPIO15 Errata RP2040-E5

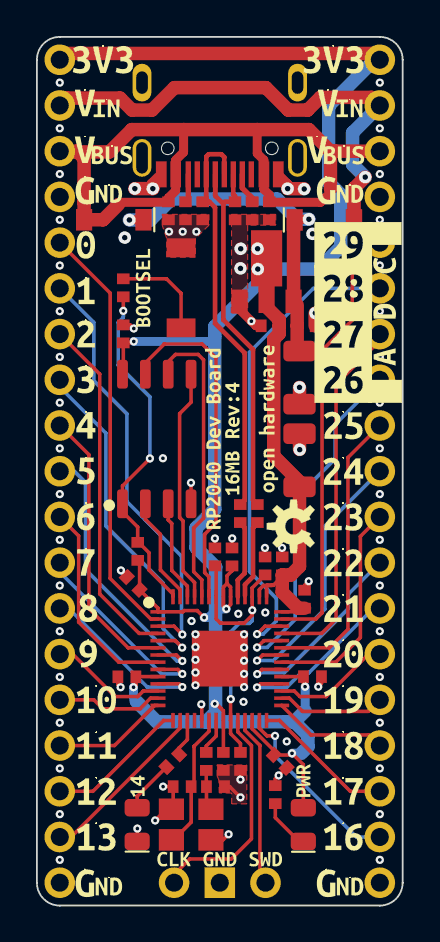
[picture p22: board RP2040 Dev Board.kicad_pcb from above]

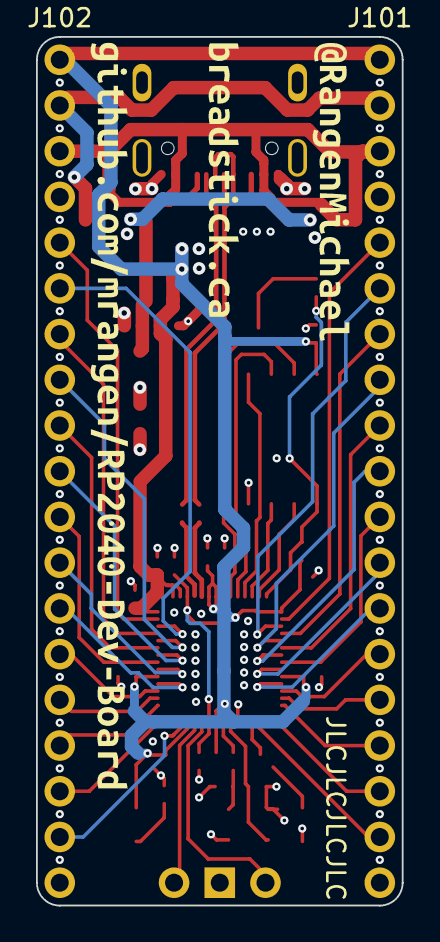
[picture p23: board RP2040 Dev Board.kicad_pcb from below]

Board: 4 copper layers, 20.3 x 48.3 mm, 105 parts (5 on the bottom side), 56 nets.

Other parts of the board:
kibuzzard-624A32A0, kibuzzard-624A32A0#2, kibuzzard-624A32A0#3, kibuzzard-624A32A0#4: G***; kibuzzard-624A32A0
kibuzzard-624A32CC, kibuzzard-624A32CC#2: G***; kibuzzard-624A32CC
kibuzzard-624A32F4, kibuzzard-624A32F4#2: G***; kibuzzard-624A32F4
kibuzzard-624A33C6, kibuzzard-624A33C6#2, kibuzzard-624A33C6#3, kibuzzard-624A33C6#4: G***; kibuzzard-624A33C6
kibuzzard-624A33D7, kibuzzard-624A33D7#2, kibuzzard-624A33D7#3, kibuzzard-624A33D7#4: G***; kibuzzard-624A33D7
kibuzzard-624A34DF: G***; kibuzzard-624A34DF
kibuzzard-624A34EB: G***; kibuzzard-624A34EB
kibuzzard-624A34F5: G***; kibuzzard-624A34F5
kibuzzard-624A34FB: G***; kibuzzard-624A34FB
kibuzzard-624A35E6: G***; kibuzzard-624A35E6
kibuzzard-624A35EE: G***; kibuzzard-624A35EE
kibuzzard-624A35F5: G***; kibuzzard-624A35F5
kibuzzard-624A35FE: G***; kibuzzard-624A35FE
kibuzzard-624A352B: G***; kibuzzard-624A352B
kibuzzard-624A353B: G***; kibuzzard-624A353B
kibuzzard-624A355B: G***; kibuzzard-624A355B
kibuzzard-624A358D: G***; kibuzzard-624A358D
kibuzzard-624A359E: G***; kibuzzard-624A359E
kibuzzard-624A3245, kibuzzard-624A3245#2: G***; kibuzzard-624A3245
kibuzzard-624A3524: G***; kibuzzard-624A3524
kibuzzard-624A3534: G***; kibuzzard-624A3534
kibuzzard-624A3542: G***; kibuzzard-624A3542
kibuzzard-624A3549: G***; kibuzzard-624A3549
kibuzzard-624A3554: G***; kibuzzard-624A3554
kibuzzard-624A3563: G***; kibuzzard-624A3563
kibuzzard-624A3578: G***; kibuzzard-624A3578
kibuzzard-624A3580: G***; kibuzzard-624A3580
kibuzzard-624A3587: G***; kibuzzard-624A3587
kibuzzard-624A3594: G***; kibuzzard-624A3594
kibuzzard-6260D8D7: G***; kibuzzard-6260D8D7
kibuzzard-6260D8EE: G***; kibuzzard-6260D8EE
kibuzzard-6260D8FE: G***; kibuzzard-6260D8FE
kibuzzard-6260D95E: G***; kibuzzard-6260D95E
kibuzzard-6260D96B: G***; kibuzzard-6260D96B
kibuzzard-6260D97B: G***; kibuzzard-6260D97B
kibuzzard-6260D939: G***; kibuzzard-6260D939
kibuzzard-6265A538: G***; kibuzzard-6265A538
kibuzzard-62659E4E: G***; kibuzzard-62659E4E
kibuzzard-62659F2B: G***; kibuzzard-62659F2B
kibuzzard-62830DE2: G***; kibuzzard-62830DE2
kibuzzard-628425F6: G***; kibuzzard-628425F6
kibuzzard-6284261D: G***; kibuzzard-6284261D
kibuzzard-6284262A: G***; kibuzzard-6284262A
kibuzzard-6284263D: G***; kibuzzard-6284263D
kibuzzard-6284264D: G***; kibuzzard-6284264D
kibuzzard-62842605: G***; kibuzzard-62842605
kibuzzard-62842613: G***; kibuzzard-62842613
kibuzzard-62842635: G***; kibuzzard-62842635
kibuzzard-62842645: G***; kibuzzard-62842645

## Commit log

2022-04-23 Initial Commit
    At this point, the design should work. I've routed the 1.1V rail that was missing from the initial prototype and fixed the pads for the LEDs. There's still work to be done, and I haven't ordered this iteration of the design yet to verify, but I believe it should work.
    [7V12000018 v4.step, BOM.xlsx, GT-TC029B-H025-L1N v1.step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]
2022-04-24 Rev 2
    Ready to order Rev2:
    -Routed missing 1.1V rail
    -Swapped LED footprints from 0603 to 0805
    -Pins 43 &44 routed to nearest decoupling cap
    -Crystal replaced with basic part and created 3D model
    -ADC silkscreen improved
    -Minor Silkscreen changes
    -Generated new gerbers, renders, and PDFs
    [BOM.xlsx, Crystal3225_24GND.step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]
2022-04-24 Generated new pick and place file
    generated new pick and place file and added it to new gerber.zip
2022-04-25 Rev 3
    JLCPCB noticed a mistake in my order, I had remnants from an early version in the gerbers folder. Cleared that out and made some updates to the board and resubmitted as Rev3. I added a GND via that was missing near a 3.3V via underneath the RP2040, added Rev 3 to the silkscreen, and nudged C207 away from the USB lines and added a GND via. Gerbers, drill, and centroid files regenerated. Rev 3 renders generated as well.
    [RP2040 Dev Board-B_Cu.gbl, RP2040 Dev Board-B_Mask.gbs, RP2040 Dev Board-B_Paste.gbp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]
2022-04-27 Typo In BOM
    The LEDs were listed as 0603 in the BOM, updated to 0805.
    [BOM.xlsx]
2022-05-16 Create RP2040 Dev Board-2022-05-16_160536.zip
2022-05-17 Made changes to schematic and PCB
    Swapped pin 0 and pin 14.
    Added missing trace from regulator to capacitors.
    Widened power distribution traces.
    Aligned LEDs.
    Adjusted Silkscreen.
    Updated Revision number to 4
    [RP2040 Dev Board.kicad_pcb, RP2040 Dev Board.kicad_sch, RP2040.kicad_sch]
2022-05-17 Create FS6xnniUUAUSUpb.png
    Added render of missing trace.
2022-05-17 Increased separation between QSPI bus lines
    Now that the LED is no longer connected to pin 0, there was room to make adjustments that allowed for better separation between the QSPI bus lines.
    [RP2040 Dev Board.kicad_pcb]
2022-05-17 Removed unconnected traces found by DRC
    During the last edit, some very short traces that didn't extend beyond the pad they were connected to were overlooked. They've now been deleted and the DRC is coming back clean.
    [RP2040 Dev Board.kicad_pcb]
2022-05-17 Modified Silkscreen and Added Renders
    Added OSHW logo and made other silkscreen changes.
    Generated a render of the front of the board.
    [RP2040 Dev Board.kicad_pcb]
2022-05-17 Generated New Gerbers, Drill, and Pos files
    [RP2040 Dev Board-B_Cu.gbl, RP2040 Dev Board-B_Mask.gbs, RP2040 Dev Board-B_Silkscreen.gbo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]
2022-05-17 Last minute board tweaks
    Made a bunch of small adjustments and made parallel paths for VBUS.
    [RP2040 Dev Board.kicad_pcb]
2022-05-18 Final Tweaks New Gerbers
    [RP2040 Dev Board-B_Cu.gbl, RP2040 Dev Board-B_Mask.gbs, RP2040 Dev Board-B_Silkscreen.gbo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]
2022-05-18 Added Prepreg JLC7628 Note
    The dimensions for the differential USB lines were calculated based off the JLC7628 prepreg.
    [RP2040 Dev Board-B_Cu.gbl, RP2040 Dev Board-B_Mask.gbs, RP2040 Dev Board-B_Silkscreen.gbo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]
2022-05-31 Create RP2040 Dev Board-2022-05-30_214038.zip
2022-05-31 Update RP2040 Dev Board.kicad_prl
2022-06-07 Created MicroPython & CircuitPython Pinout Diagrams
2022-06-15 Board Dimensions
    Added board dimensions to User Drawings layer and exported images to the Renders directory. Updated date on both schematic and pcb.
    [RP2040 Dev Board.kicad_pcb, RP2040 Dev Board.kicad_sch, RP2040.kicad_sch]
2022-06-15 Tindie 2x3 Pinouts for CircuitPython & MicroPython
2022-06-22 Create RP2040-Dev-Board.svg
    Began creating SVG model of board for Fritzing

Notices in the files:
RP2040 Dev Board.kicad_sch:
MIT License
